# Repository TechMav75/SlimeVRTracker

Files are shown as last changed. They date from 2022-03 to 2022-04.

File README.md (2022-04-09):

# SlimeVRTracker

This is for the carrier board for the SlimeVR Tracker at https://docs.slimevr.dev/

The files were designed and exported in Fritzing https://fritzing.org/

There are 3 sets of jumper pads on the back of the board. If you are using an MPU IMU, you will need to solder the left two pads together of the right hand triple pad. It's labled MPU under it. If you're using a BNO IMU, you will need to solder the right two pads of the right hand triple pad, and the both pairs of the other two pads. These are to route the correct signals to the Aux board.

Version Differences: V6 and V7 both work fine, it's a matter of preference on where the power switch is.

v6 Aux Board: These are good. 

v6 Tracker Board: This has the power switch on the side under the charging board

v7 Tacker Board: This has the power switch on the end, under the USB C port. This was moved to allow evrything that you need to access to protrude through the lid of the case. 

Pimoroni Tracker v1 and Pimoroni Tracker Aux v1 are for the Pimoroni PIM448 IMU board, that has the ICM20948 sensor on it.

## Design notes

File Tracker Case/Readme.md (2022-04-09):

This is the STL's and OpenSCAD files for the cases for the non-Pimoroni units.

STL and OpenSCAD files for the Aux Tracker case
AuxTracker Lid v8.stl
AuxTracker v8.scad
AuxTracker v8.stl

STL and OpenSCAD files for the Tracker case

Tracker Lid v9.stl
Tracker v10.scad
Tracker v10.stl 

You will also need M3x5 machine screws and threaded inserts to match. The inserts I used are closed bottom. There are holes beside the insert hole, for injecting liquid resin with a syringe and 18ga blunt needle.

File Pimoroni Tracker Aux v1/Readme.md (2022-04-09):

These are the Aux board files for the Pimoroni PIM488

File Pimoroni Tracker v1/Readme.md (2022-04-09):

These are the tracker board files for the Pimoroni PIM488 board

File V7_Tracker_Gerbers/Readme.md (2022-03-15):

Moved the switch to the end of the board, so it can protrude through the cover plate to be more usable.

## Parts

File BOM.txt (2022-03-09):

RJ-45 sockets
https://www.digikey.com/en/products/detail/amphenol-cs-fci/54602-908LF/1001360

Side mount switches
https://www.digikey.com/en/products/detail/te-connectivity-alcoswitch-switches/1825232-1/4021554

MPU6050 Boards
https://www.aliexpress.com/item/1005001864385331.html

WeMos D1 Mini Pro Boards
https://www.aliexpress.com/item/1005001824235269.html

1200mAh Batteries, 804040
https://www.aliexpress.com/item/1005002559604104.html

TP4056 Charging Boards
https://www.aliexpress.com/item/32649780468.html

180K Resistor
https://www.mouser.com/ProductDetail/603-MFR-25FTE52-180K

15817 Diode
https://www.mouser.com/ProductDetail/833-1N5817-TP

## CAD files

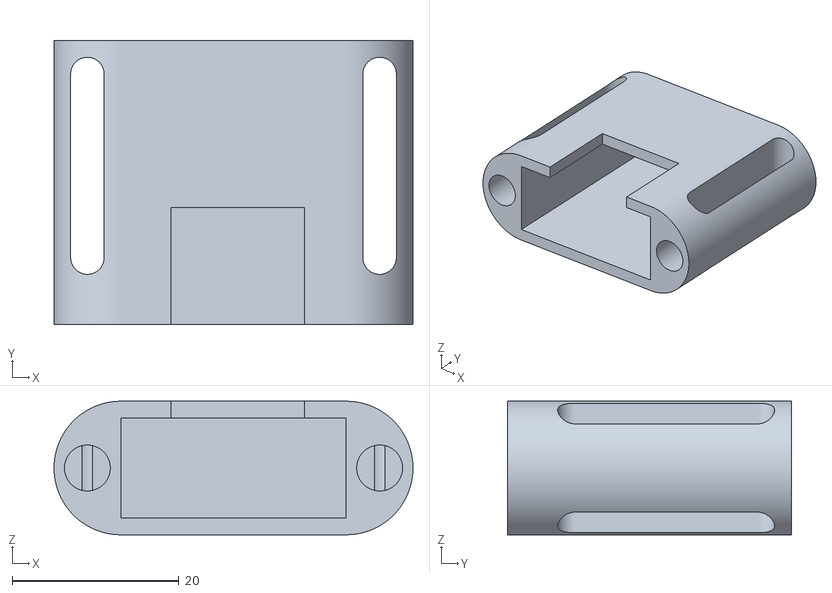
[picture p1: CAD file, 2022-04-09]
Tracker Case/AuxTracker v8.stl
43.0 x 34.0 x 16.0

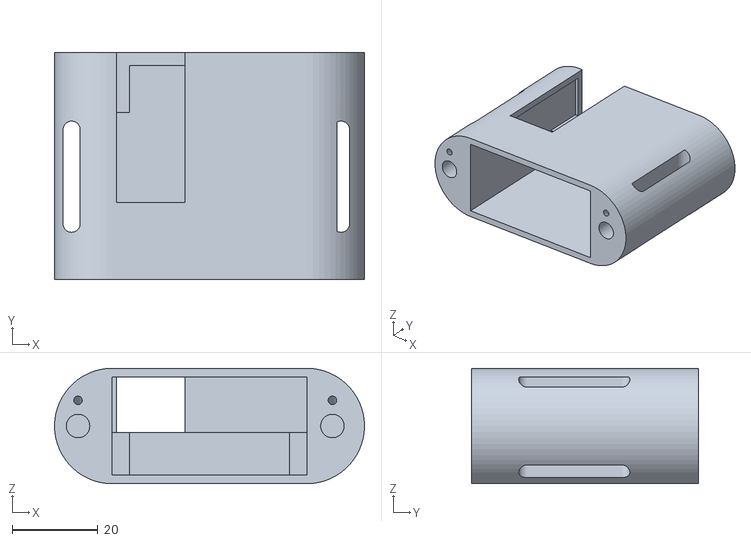
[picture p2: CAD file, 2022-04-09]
Tracker Case/Tracker v10.stl
72.5 x 53.0 x 27.0

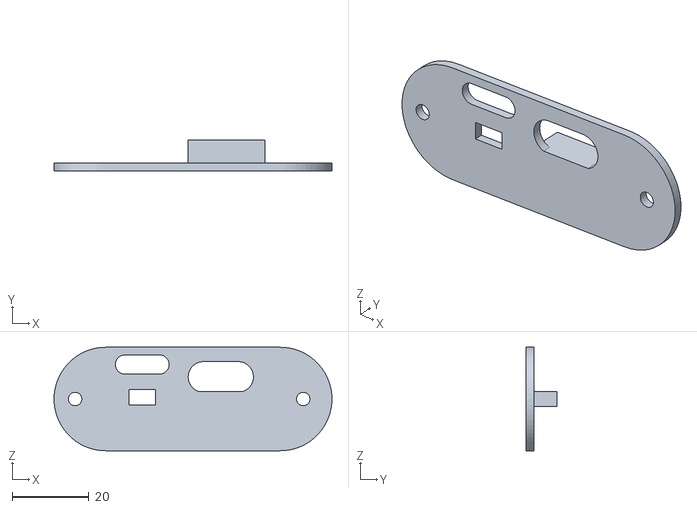
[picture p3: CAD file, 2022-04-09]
Tracker Case/Tracker Lid v9.stl
72.5 x 8.00 x 27.0

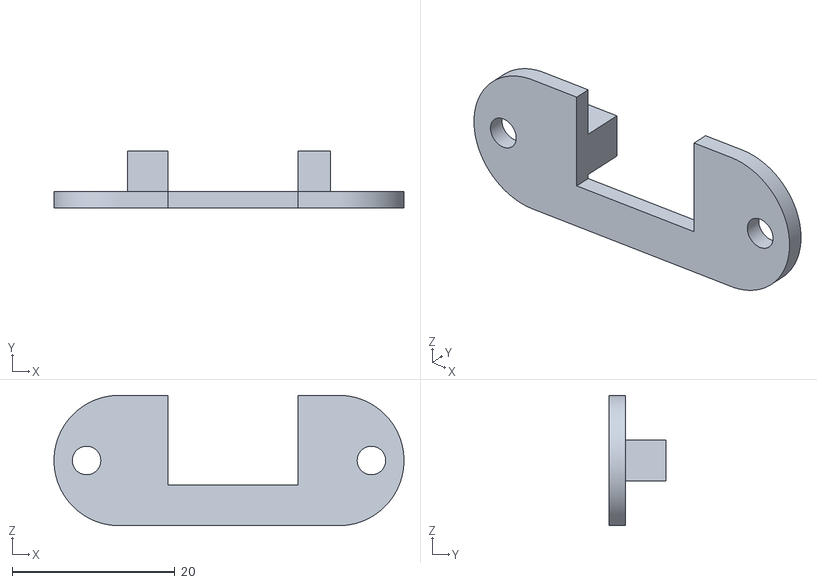
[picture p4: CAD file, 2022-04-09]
Tracker Case/AuxTracker Lid v8.stl
43.0 x 7.00 x 16.0

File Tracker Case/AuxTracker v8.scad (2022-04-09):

$fn=360;

WALL=2;  //Wall thickness
BOARD=[27,32,12];;      //X dimension of board 
                        //Y dimension of board (does not include jack overhang)
                        //Z dimension of board and jack
JACK=[16,18,16,6,-4];   //X dimension of jack  
                        //Y dimension of jack 
                        //Z dimension of jack
                        //X offset from edge of board
                        //Y offset from edge of board
BELT=[26,4];            //Width of belt
                        //Belt Gap
    
Case() ;
//Lid() ;

    
module Aux_Board() {
    union () {
        cube([BOARD[0],BOARD[1],BOARD[2]]);
        translate([JACK[3],JACK[4]-WALL*3,0]) cube([JACK[0],JACK[1]+WALL*3,JACK[2]+WALL]);
        }
    }    

module BeltSlot() {
    hull() {
        cylinder(d=BELT[1],h=25);
        translate([0,BELT[0]-BELT[1],0]) cylinder(d=BELT[1],h=25);
    }
}

//color ("red") Aux_Board() ;

module Case() {
difference() {
hull() {    
translate([(JACK[2]/2+WALL),0,(JACK[2]/2)]) rotate ([270,0,0]) cylinder(d=JACK[2],h=BOARD[1]+WALL);
translate([(JACK[2]/2+WALL+BOARD[0]),0,(JACK[2]/2)]) rotate ([270,0,0]) cylinder(d=JACK[2],h=BOARD[1]+WALL);
}
translate([JACK[2]/2+WALL,0,WALL]) Aux_Board() ;
translate([WALL*3,WALL*4,0]) BeltSlot() ;
translate([WALL*7+BOARD[0],WALL*4,0]) BeltSlot() ;
translate([(JACK[2]+BOARD[0])/2+WALL,BOARD[1]-WALL,0]) cylinder(d=2,h=WALL*2);

translate([(JACK[2]/2-2),0,(JACK[2]/2)]) rotate ([270,0,0]) ScrewHole();
translate([(JACK[2]/2+WALL*3+BOARD[0]),0,(JACK[2]/2)]) rotate ([270,0,0]) ScrewHole();
}
}

module ScrewHole() {
    hull() {
        cylinder(d=5.5,h=0.1);
        translate([0,0,6]) cylinder(d=6.5,h=0.1);
    }
}

module Lid() {
    union() {
difference() {
translate([0,-WALL,0]) hull() {    
translate([(JACK[2]/2+WALL),0,(JACK[2]/2)]) rotate ([270,0,0]) cylinder(d=JACK[2],h=WALL);
translate([(JACK[2]/2+WALL+BOARD[0]),0,(JACK[2]/2)]) rotate ([270,0,0]) cylinder(d=JACK[2],h=WALL);
}
translate([JACK[2]/2+WALL,0,WALL+3]) Aux_Board() ;

translate([(JACK[2]/2-2),-2,(JACK[2]/2)]) rotate ([270,0,0]) cylinder(d=3.5,h=5);
translate([(JACK[2]/2+WALL*3+BOARD[0]),-2,(JACK[2]/2)]) rotate ([270,0,0]) cylinder(d=3.5,h=5);

}
translate([11,-2,5.5]) cube ([5,7,5]);
translate([32,-2,5.5]) cube ([4,7,5]);
}
}

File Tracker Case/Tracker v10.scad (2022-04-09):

$fn=60;

WALL=2;                 //Wall thickness
BOARD=[45.5,51,13];     //X dimension of board 
                        //Y dimension of board (does not include jack 
                        //  overhang)
                        //Z dimension of board and jack
SWITCH=[3,7,4,6];      //X dimension for switch
                        //Y dimension for switch
                        //Z dimension for switch 
JACK=[16,38,16,1,18];   //X dimension of jack  
                        //Y dimension of jack 
                        //Z dimension of jack
                        //X offset from edge of board
                        //Y offset from edge of board
BELT=[26,4];            //Width of belt
                        //Belt Gap
BATTERY=[45.5,40,11];      //X dimension for Battery
                        //Y dimension for Battery
                        //Z dimension for Battery

Case() ;
//Lid() ;
  
//ScrewHole() ;



module Board() {
    union () {
        cube([BOARD[0],BOARD[1],BOARD[2]]);
        translate([JACK[3],JACK[4],0]) cube([JACK[0],JACK[1],JACK[2]]);
        translate([SWITCH[3],-SWITCH[0],0]) cube([SWITCH[1],SWITCH[0],SWITCH[2]]);
        }
    }    

module BeltSlot() {
    hull() {
        cylinder(d=BELT[1],h=25);
        translate([0,BELT[0]-BELT[1],0]) cylinder(d=BELT[1],h=25);
    }
}

module Battery() {
    cube([BATTERY[0],BATTERY[1],BATTERY[2]]);
    translate([WALL*2,0,0]) cube([BATTERY[0]-WALL*4,BOARD[1],BATTERY[2]]);
}

module ScrewHole() {
    hull() {
        cylinder(d=5.5,h=0.1);
        translate([0,0,6]) cylinder(d=6.5,h=0.1);
    }
    hull() {
        translate([0,-6,0]) cylinder(d=2,h=0.1);
        translate([0,-2.5,6]) cylinder(d=2,h=0.1);
    }
}
    

module Case() {
difference() {
hull() {    
translate([(JACK[2]/2+WALL+BATTERY[2]/2),0,(JACK[2]/2)+BATTERY[2]/2]) rotate ([270,0,0]) cylinder(d=JACK[2]+BATTERY[2],h=BOARD[1]+WALL);
translate([(JACK[2]/2+WALL+BOARD[0]+BATTERY[2]/2),0,(JACK[2]/2)+BATTERY[2]/2]) rotate ([270,0,0]) cylinder(d=JACK[2]+BATTERY[2],h=BOARD[1]+WALL);
}

translate([JACK[2]/2+WALL+BATTERY[2]/2,0,WALL+BATTERY[2]-1]) Board() ;
translate([WALL*3,WALL*3+SWITCH[1],0]) BeltSlot() ;
translate([WALL*9+BOARD[0]+BATTERY[2]/2,WALL*3+SWITCH[1],0]) BeltSlot() ;
translate([JACK[2]/2+WALL+BATTERY[2]/2,-1,WALL]) Battery() ;

translate([7.5,0,(JACK[2]/2)+BATTERY[2]/2]) rotate ([270,0,0]) ScrewHole();
translate([(JACK[2]/2+WALL*4+BOARD[0]+BATTERY[2]/2),0,(JACK[2]/2)+BATTERY[2]/2]) rotate ([270,0,0]) ScrewHole();
}
}

module Lid() {
    union () {
    difference() {
hull() {    
translate([(JACK[2]/2+WALL+BATTERY[2]/2),-WALL,(JACK[2]/2)+BATTERY[2]/2]) rotate ([270,0,0]) cylinder(d=JACK[2]+BATTERY[2],h=WALL);
translate([(JACK[2]/2+WALL+BOARD[0]+BATTERY[2]/2),-WALL,(JACK[2]/2)+BATTERY[2]/2]) rotate ([270,0,0]) cylinder(d=JACK[2]+BATTERY[2],h=WALL);
}
translate([JACK[2]/2+WALL+BATTERY[2]/2,0,WALL+BATTERY[2]-1]) Board() ;
translate([20.5,-2,22.5]) rotate([270,0,0]) CJack(5) ;
translate([41,-2,19.25]) rotate([270,0,0]) CJack(8) ;

translate([7.5,-2,(JACK[2]/2)+BATTERY[2]/2]) rotate ([270,0,0]) cylinder(d=3.5,h=BOARD[1]+WALL);
translate([(JACK[2]/2+WALL*4+BOARD[0]+BATTERY[2]/2),-2,(JACK[2]/2)+BATTERY[2]/2]) rotate ([270,0,0]) cylinder(d=3.5,h=BOARD[1]+WALL);

}
translate([37,-2,11.5]) cube([20,8,4]);
}
}


module CJack(D) {
    hull() {
        cylinder(d=D,h=5);
        translate([9,0,0]) cylinder(d=D,h=5);
    }
}
